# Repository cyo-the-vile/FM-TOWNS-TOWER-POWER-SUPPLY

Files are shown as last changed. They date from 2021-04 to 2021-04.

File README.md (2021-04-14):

# FM-TOWNS-TOWER-POWER-SUPPLY
Replacement Power supply for FMT Tower units

This is a replacement for the aging FM Towns power supply.  It's a very well known fact in the niche FM Towns community that the power supply in the Tower models has chronic failure issues. This power supply revolves around using an ACDC converter with an ITX Pico PSU controlled by an Arduino Pro Micro.

This power supply can be used for the following FM Towns computers:

-MODEL 1
-MODEL 2
-SF
-SH
-1F
-2F
-1H
-2H
-10F
-20F
-40H
-80H
-CX10
-CX20
-CX40
-CX100
-SF2
-SH2

To assemble you need to program an Arduino Pro Micro in the Arduino IDE.  Once the Arduino is programmed solder the pin headers and Arduino to the PCB.

After that simply solder everything else.

The Arduino runs on the 5V Standby of the Pico PSU and controls the power on via original power button and also the TownsOS power off feature.

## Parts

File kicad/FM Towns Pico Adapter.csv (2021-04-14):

Id | Designator | Package | Quantity | Designation | Supplier and ref
1 | REF**,REF**,REF** | MountingHole_2.1mm | 3 | MountingHole_2.1mm
2 | REF**,REF**,REF**,REF**,REF**,REF** | MountingHole_4.3mm_M4 | 6 | MountingHole_4.3mm_M4
3 | PAD4,PAD3,PAD2,PAD1 | MountingHole_3.5mm_Pad_Via | 4 | MountingHole_3.5mm_Pad_Via
4 | FAN1 | PinHeader_1x02_P2.54mm_Vertical | 1 | Conn_01x02
5 | G*** | townslogo | 1 | LOGO
6 | J2 | PCN1344S254DS71 | 1 | PCN13-44S-2.54DS_71_
7 | J1 | ATX24_RIGHT_ANGLE | 1 | ATX24RH
8 | Q1 | SOT23 | 1 | BC847
9 | R4,R1,R2 | R0603 | 3 | 1K
10 | PSON1,PSOFF1 | JP1 | 2 | JP1E
11 | IC1 | SO14 | 1 | 7400D
12 | C1,C2,C3 | C0805 | 3 | 100nF
13 | STBY_LED1,5V_LED1,12V_LED1 | CHIPLED_0805 | 3 | LEDCHIPLED_0805
14 | R5,R6 | R0603 | 2 | 220R
15 | R7 | R0603 | 1 | 680R

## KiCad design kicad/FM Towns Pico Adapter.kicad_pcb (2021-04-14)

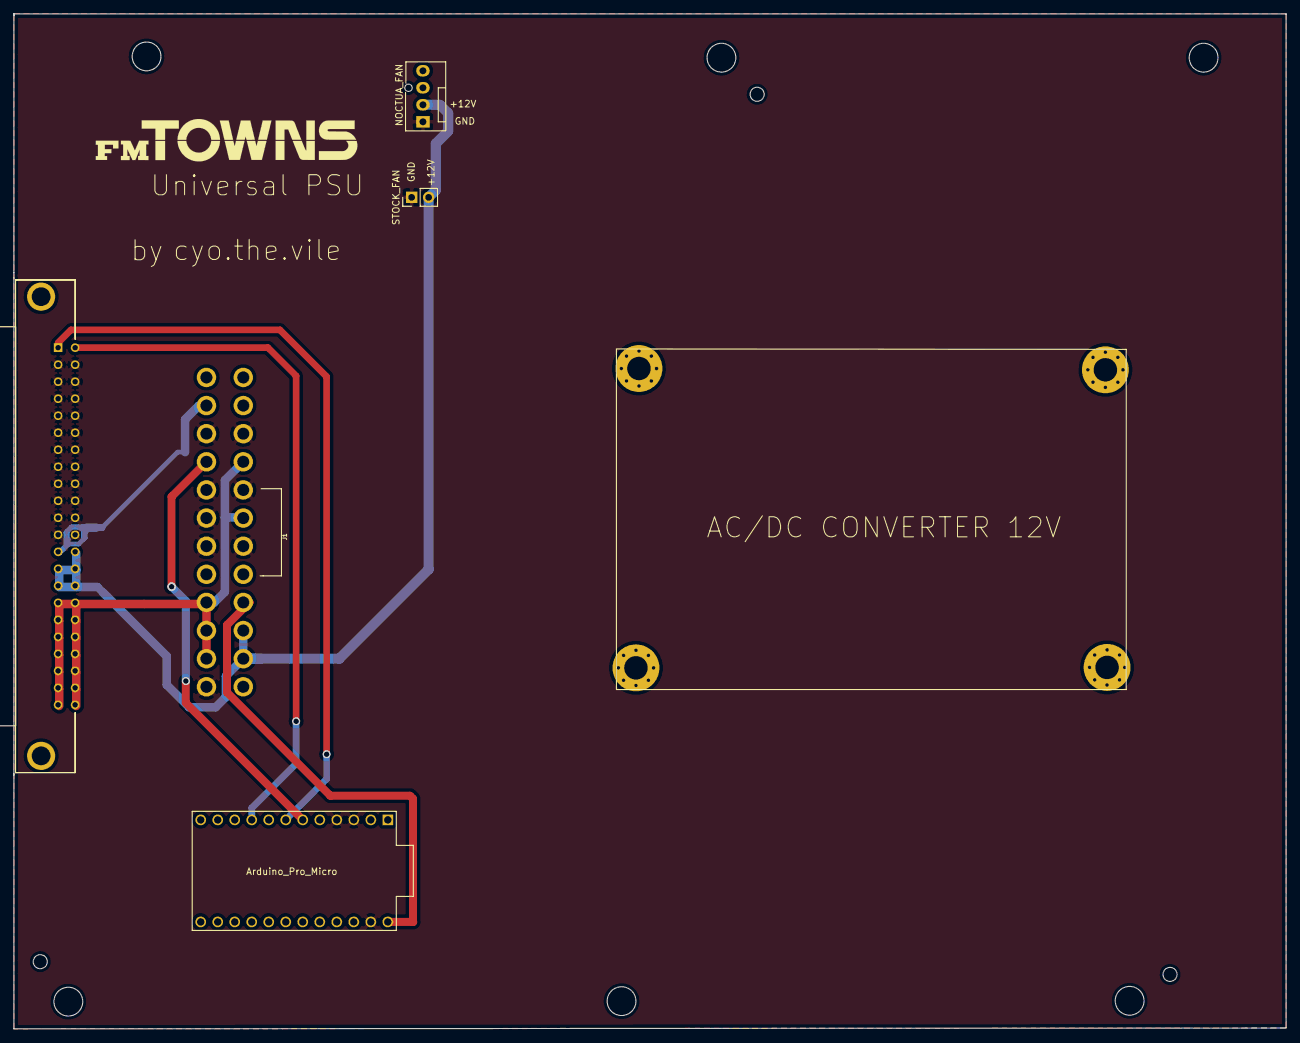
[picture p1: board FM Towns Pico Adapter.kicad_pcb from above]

Board: 2 copper layers, 190.0 x 151.6 mm, 9 parts (0 on the bottom side), 8 nets.

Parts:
J1: ATX24RH; ATX24_RIGHT_ANGLE
J2: PCN13-44S-2.54DS_71_; PCN1344S254DS71
NOCTUA_FAN: 47053-1000; FanPinHeader_1x04_P2.54mm_Vertical
PAD1, PAD2, PAD3, PAD4: MountingHole_3.5mm_Pad_Via
STOCK_FAN: Conn_01x02; PinHeader_1x02_P2.54mm_Vertical
U1: ProMicro

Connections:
+5V: J1.4, J1.6, J1.21, J1.22, J1.23, J2.A16, J2.A17, J2.A18, J2.A19, J2.A20, J2.A21, J2.A22, J2.B16, J2.B17, J2.B18, J2.B19, J2.B20, J2.B21, J2.B22
+12V: J1.10, J1.11, J2.A14, J2.A15, J2.B13, J2.B14, J2.B15, NOCTUA_FAN.2, STOCK_FAN.2
-12V: J1.14, J2.A13
/5V_STBY: J1.9, U1.24
/FM_PS_OFF_N: J2.A1, U1.7
/FM_PS_ON_N: J2.B1, U1.9
/PS_ON: J1.16, U1.6
GND: J1.3, J1.5, J1.7, J1.15, J1.17, J1.18, J1.19, J1.24, J2.A2, J2.A3, J2.A4, J2.A5, J2.A6, J2.A7, J2.A8, J2.A9, J2.A10, J2.A11, J2.A12, J2.B2, J2.B3, J2.B4, J2.B5, J2.B6, J2.B7, J2.B8, J2.B9, J2.B10, J2.B11, J2.B12, NOCTUA_FAN.1, STOCK_FAN.1, U1.3, U1.4, U1.23

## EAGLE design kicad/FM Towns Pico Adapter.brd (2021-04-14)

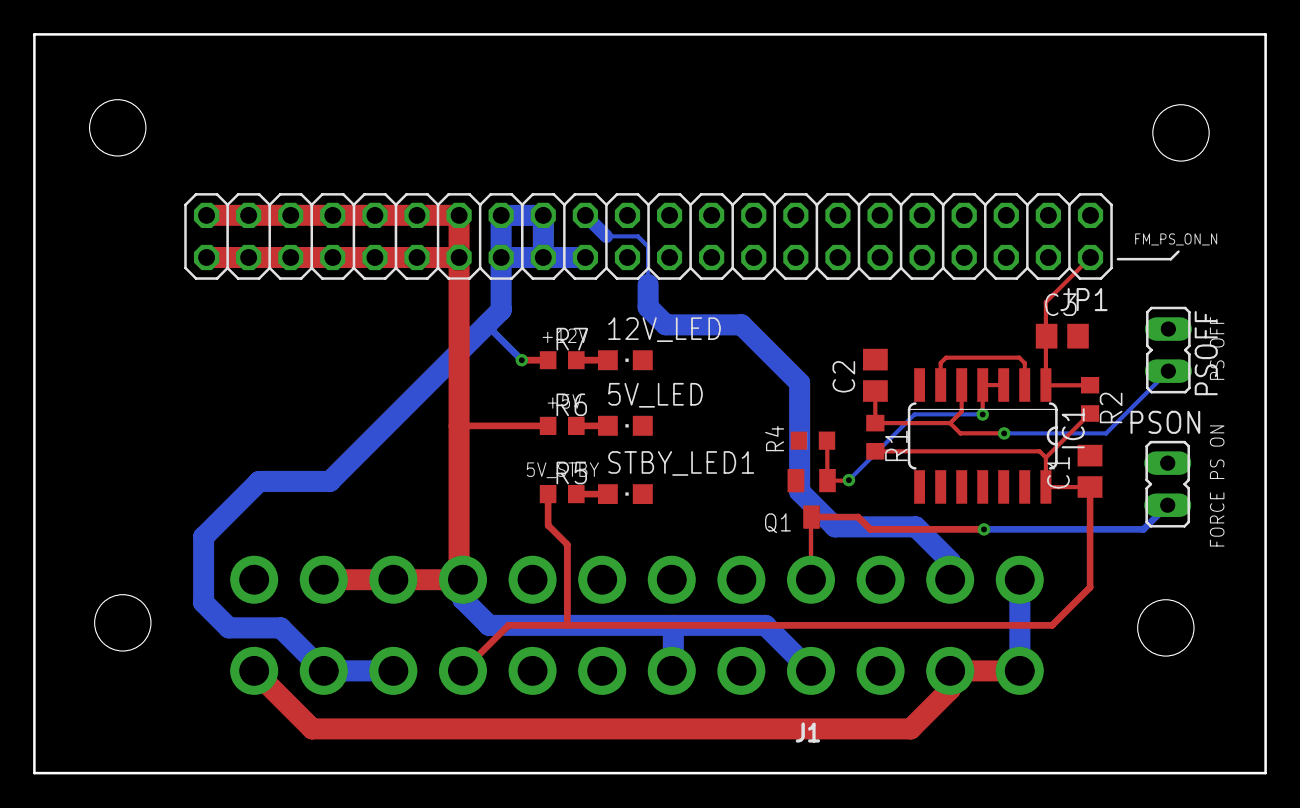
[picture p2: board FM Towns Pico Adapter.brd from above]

Board: 2 copper layers, 74.3 x 44.6 mm, 18 parts (0 on the bottom side), 14 nets.

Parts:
5V_LED, 12V_LED: CHIPLED_0805
C1, C2, C3: 100nF; C0805
IC1: 74HC00D; SO14
J1: ATX24RH; ATX24_RIGHT_ANGLE
JP1: 2X22
PSOFF: JP1
PSON: JP1
Q1: BC847; SOT23
R1, R2, R4: 1K; R0603
R5, R6: 220R; R0603
R7: 680R; R0603
STBY_LED1: CHIPLED_0805

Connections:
5V_STBY: C1.1, IC1.14, J1.9, R1.2, R2.2, R5.1
+3V3: J1.1, J1.2, J1.12, J1.13
+5V: J1.4, J1.6, J1.21, J1.22, J1.23, JP1.31, JP1.32, JP1.33, JP1.34, JP1.35, JP1.36, JP1.37, JP1.38, JP1.39, JP1.40, JP1.41, JP1.42, JP1.43, JP1.44, R6.1
+12V: J1.10, J1.11, JP1.26, JP1.27, JP1.28, JP1.29, JP1.30, R7.1
-12V: J1.14, JP1.25
ATX_PS_ON_N: J1.16, PSON.1, Q1.3
FM_PS_OFF_N: C2.1, IC1.5, PSOFF.2, R1.1
FM_PS_ON_N: C3.1, IC1.1, JP1.2, R2.1
GND: 5V_LED.C, 12V_LED.C, C1.2, C2.2, C3.2, IC1.7, IC1.9, IC1.10, IC1.12, IC1.13, J1.3, J1.5, J1.7, J1.15, J1.17, J1.18, J1.19, J1.24, JP1.3, JP1.4, JP1.5, JP1.6, JP1.7, JP1.8, JP1.9, JP1.10, JP1.11, JP1.12, JP1.13, JP1.14, JP1.15, JP1.16, JP1.17, JP1.18, JP1.19, JP1.20, JP1.21, JP1.22, JP1.23, JP1.24, PSOFF.1, PSON.2, Q1.2, R4.1, STBY_LED1.C
unnamed: IC1.2, IC1.6
unnamed: R5.2, STBY_LED1.A
unnamed: 5V_LED.A, R6.2
unnamed: 12V_LED.A, R7.2
PS_ON_TTL: IC1.3, IC1.4, Q1.1, R4.2

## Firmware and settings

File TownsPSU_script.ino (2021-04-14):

String chkDiv = "off";

int pushPin = 4;    //Solder this wire to POWER ON-OFF Button on Towns

int psonPin = 3;    //Soldier this wire to PS_ON line of ATX Power Supply

int osPin = 6;      //Soldier this wire to OFF Wire on Towns Power Supply for TownsOS power off

 

void changePower(){

    if(chkDiv == "off"){

        digitalWrite(psonPin, LOW);

        chkDiv = "on";

    }else{

        digitalWrite(psonPin, HIGH);

        chkDiv = "off";

    }

}

void setup(void) {

    pinMode(pushPin, INPUT_PULLUP); //Power Switch Button

    pinMode(osPin, INPUT_PULLUP); //OS Power Button 

    pinMode(psonPin, OUTPUT); //ATX Power On off

    digitalWrite(psonPin, HIGH);

}

 

void loop(void) {

    if (digitalRead(pushPin) == LOW) {

        changePower();

        delay(500); 

    }else if (digitalRead(osPin) == LOW) {

        changePower();

        delay(500); 

}
}

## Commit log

2021-04-14 GERBERS
    Factory output files for PCB fabrication
    [FM Towns Pico Adapter-B_Mask.gbr, FM Towns Pico Adapter-B_Paste.gbr, FM Towns Pico Adapter-B_SilkS.gbr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]
2021-04-14 Kicad Files
    Kicad files for editing PCB
    [FM Towns Pico Adapter.brd, FM Towns Pico Adapter.csv, FM Towns Pico Adapter.kicad_pcb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]
2021-04-14 Arduino Script
    Script to configure Arduino Nano
2021-04-14 BOM file
    Bill of materials
2021-04-14 Update BOM

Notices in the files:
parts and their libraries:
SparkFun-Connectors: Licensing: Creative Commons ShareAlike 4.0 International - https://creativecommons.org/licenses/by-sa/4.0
